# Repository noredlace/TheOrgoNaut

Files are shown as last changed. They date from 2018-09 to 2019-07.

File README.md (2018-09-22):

# TheOrgoNaut66

A design by u/lizardsticks

A an ergonomic ortholinear 60% board. Inspiration from the atreus with a twist on the modifiers and keys to fit most keycap designs. <br /> 

Nonstandard keycaps include the 2.25u Novelty on the left side. This keycap is meant to be used with either the Enter Key or a Novelty Enter Key. 

The left shift key was chosen to be a 2.75u with the right shift being a split shift 1.75u + 1u key.

I suppose the inner column 1u keycaps for 5,3 nd 5,4 could potentially be difficult to find, in the meantime the numpad of a keycap set should suffice.

This allows the keyboard to be symmetrical while having good compatibility with most base keycap sets.

KLE
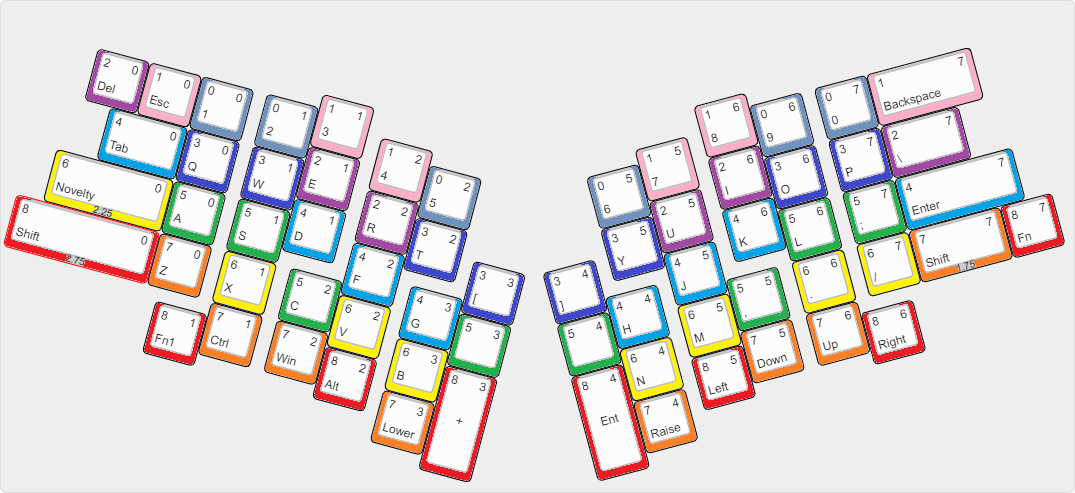
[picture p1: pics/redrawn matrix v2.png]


The color code helps identify the rows of diodes that will be used. The spacing allows for me to visualize the columns. The actual PCB won't have the spacing that you see on the left and right side. The triangle spacing in the middle will stay.

Before this, I had made the matrix based off the position of keys, which made tracing messy due to a multitude of crossed traces. Thus I made necessary changes to allow for cleaner traces and minimal vias.

You can also see the row and column numbers to visualize the schematic.

Schematic was done in a 9 x 8 layout. This is due to the 66 keys on the OrgoNaut. <br />
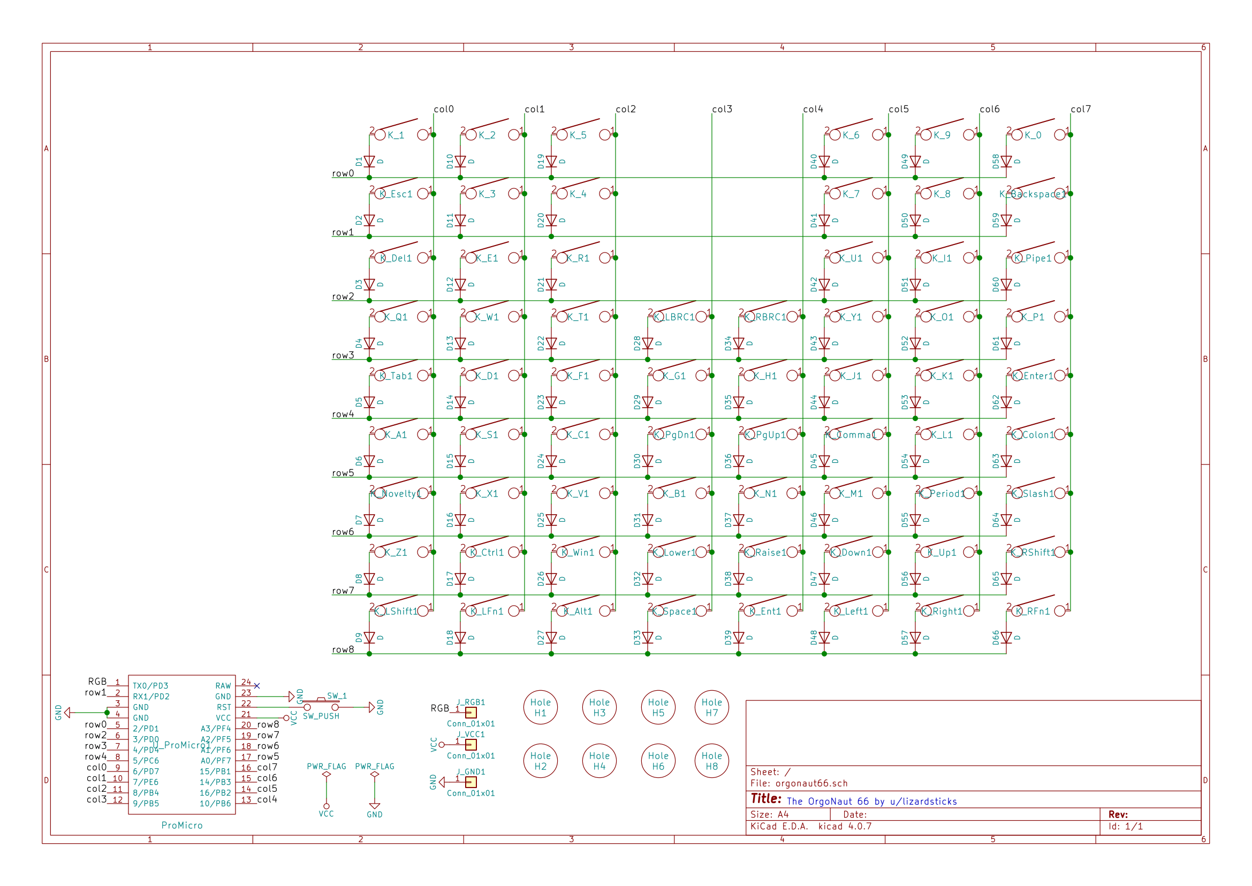
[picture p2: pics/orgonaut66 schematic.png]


PCB Dimensions are 148x362mm(5.81x14.25 inches) 
Front PCB
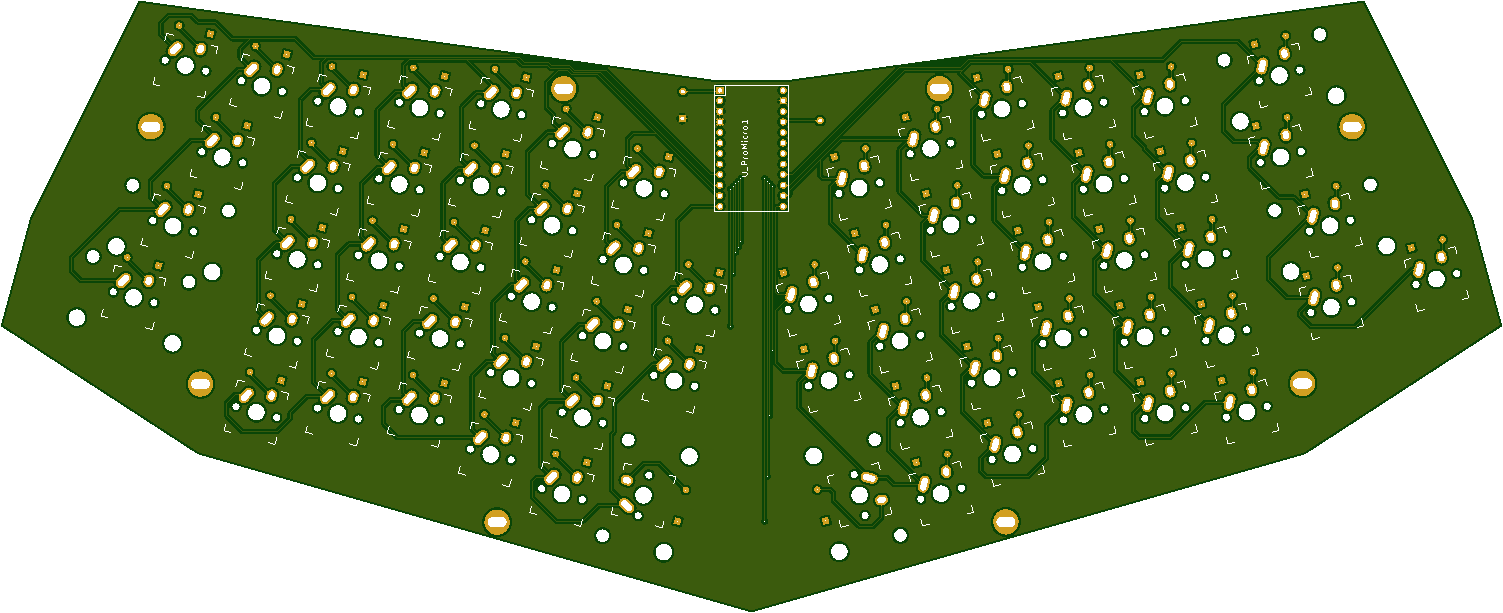
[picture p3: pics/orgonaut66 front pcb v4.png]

Back PCB
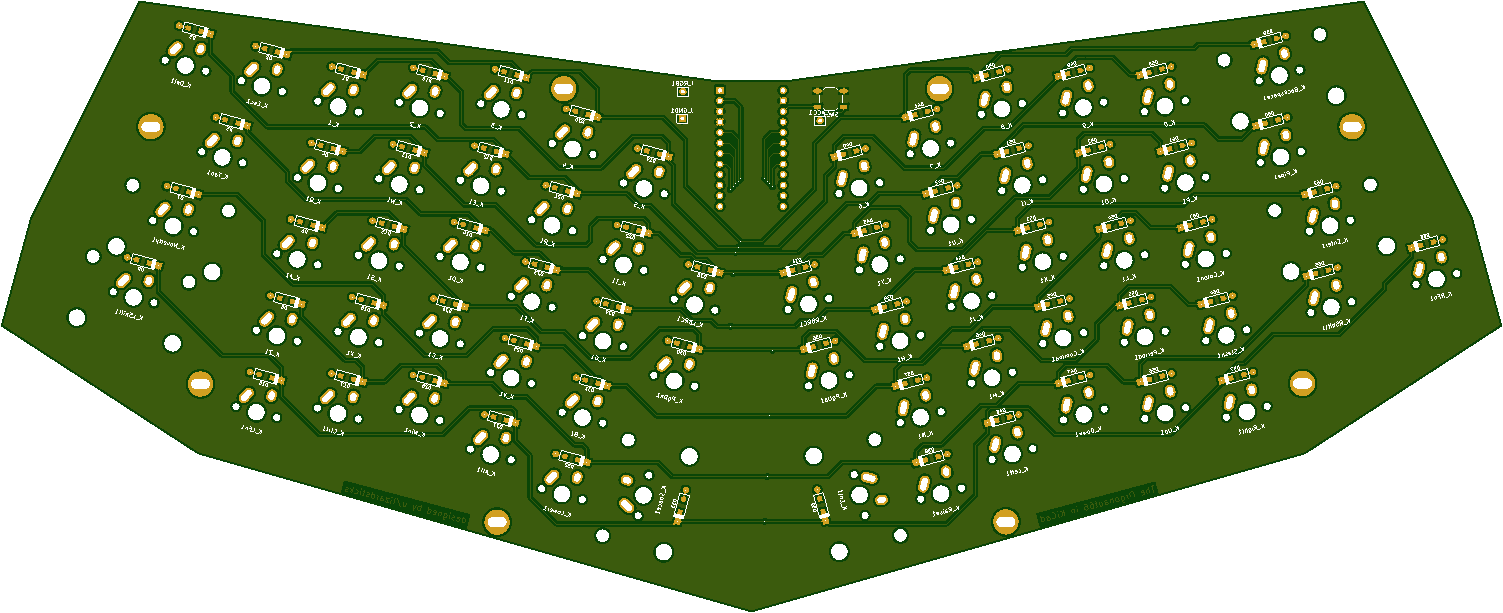
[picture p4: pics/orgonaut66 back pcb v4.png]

As you can see in the photos, the pcb is relatively clean in terms of the tracing. Of course its relative to how much of a mess my previous trace attempts have been.

Update v2 attempted to create aesthetically pleasing tracing. significant focus on how tracing to the pro micro 

Update v3 changed the pictures from KiCad's renderer to a gerber viewer provided by EasyEDA

Update v4 brought uniform ground planes to cover both front and back of the pcb. As well as changing the through hole footprints from m2 screw holes to pok3r style holes

# Major Update
The PCBs have been ordered and delivered courtesy of EasyEDA. The PCBs have been tested and all holes are currently registering correct keystrokes for the simple keyboard layout that has been made.

PCBs just delivered
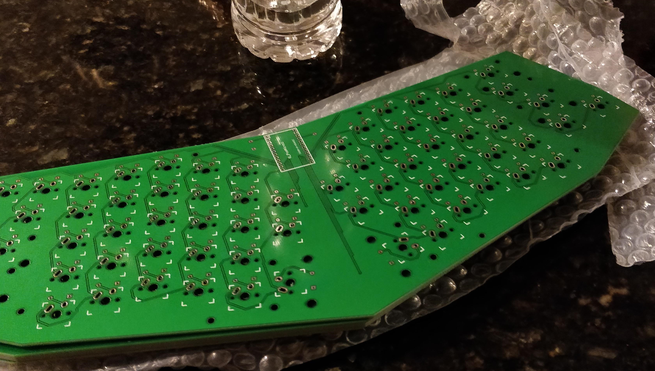
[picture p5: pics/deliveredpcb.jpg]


PCB Soldered with diodes and socketed pro micro
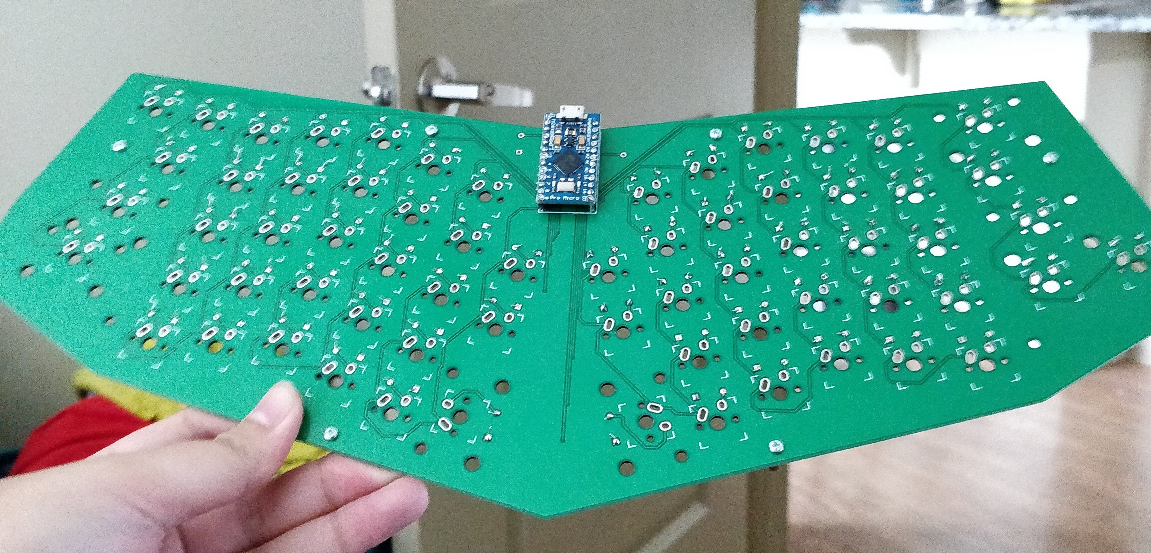
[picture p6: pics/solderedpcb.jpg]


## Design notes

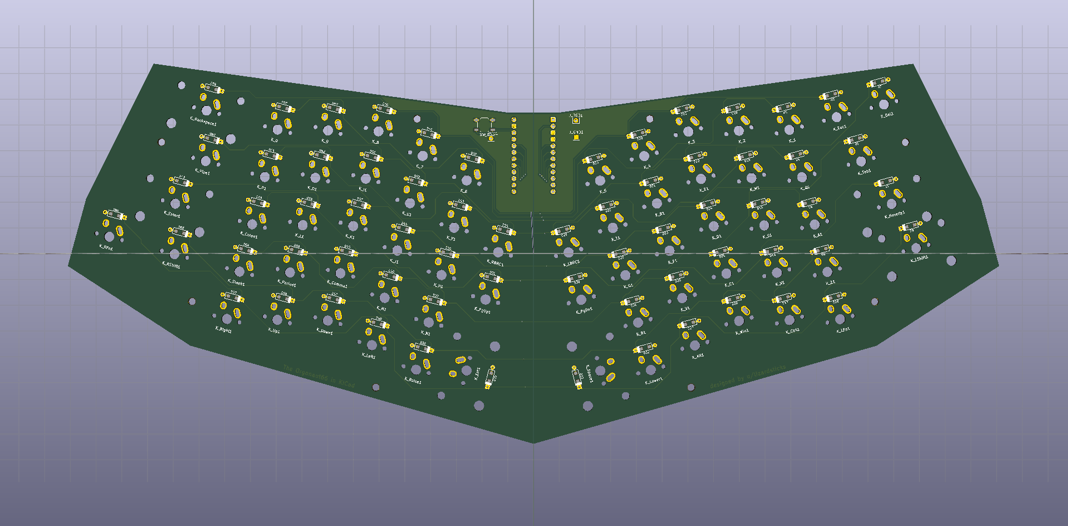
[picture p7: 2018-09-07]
pics/orgonaut66 back pcb v2.png

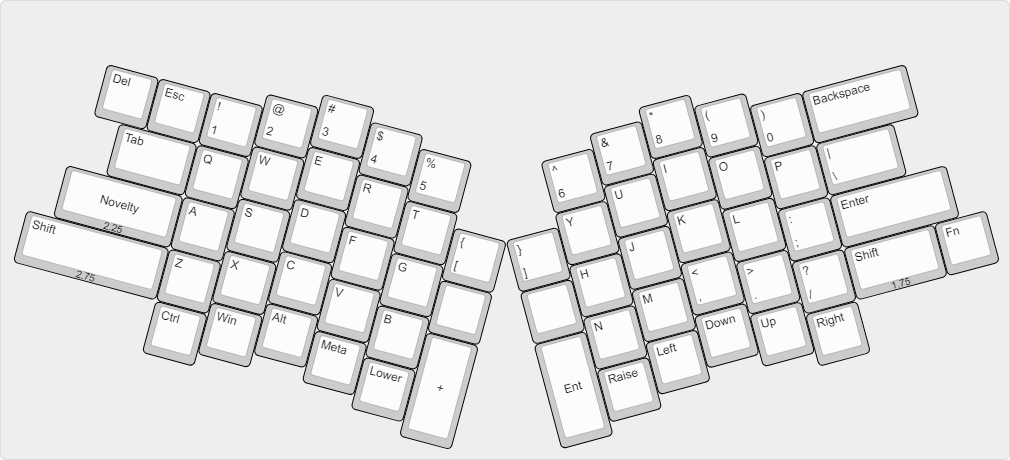
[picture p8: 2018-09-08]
pics/orgonaut layout.png

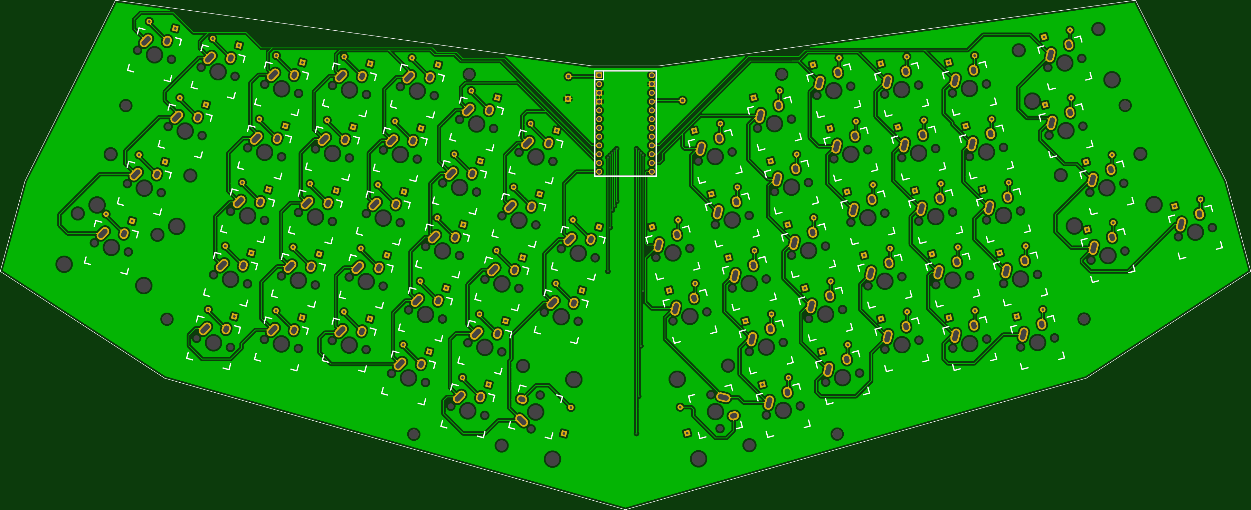
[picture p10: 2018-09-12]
pics/orgonaut66 front pcb v3.png

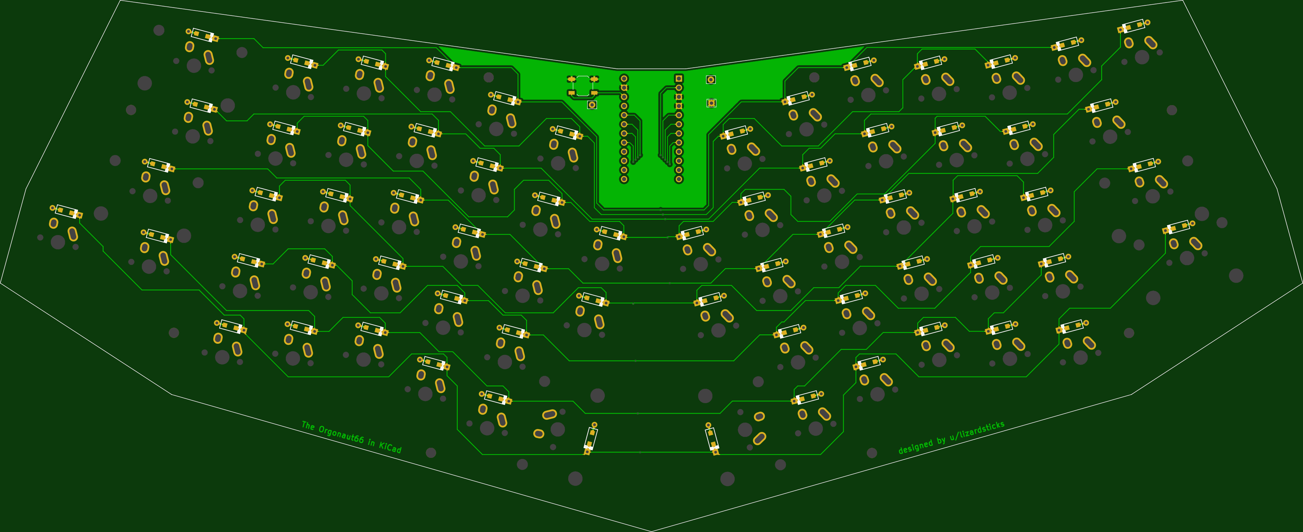
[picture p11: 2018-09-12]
pics/orgonaut66 back pcb v3.png

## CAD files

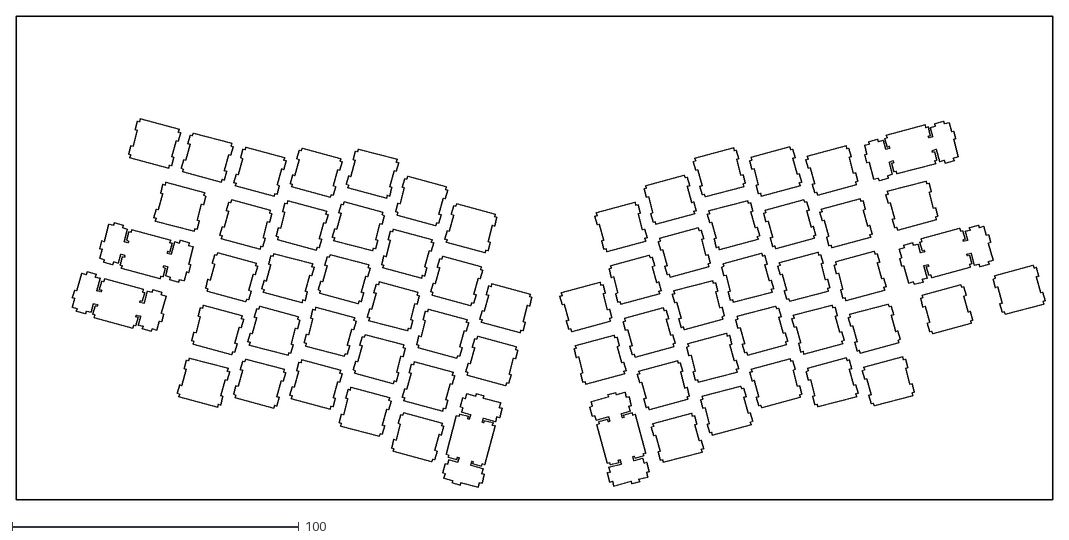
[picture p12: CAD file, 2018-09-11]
orgonaut66/fa1955e74fefcd2b1390044c22b81dd708fb88fe_switch.dxf
361.7 x 168.9

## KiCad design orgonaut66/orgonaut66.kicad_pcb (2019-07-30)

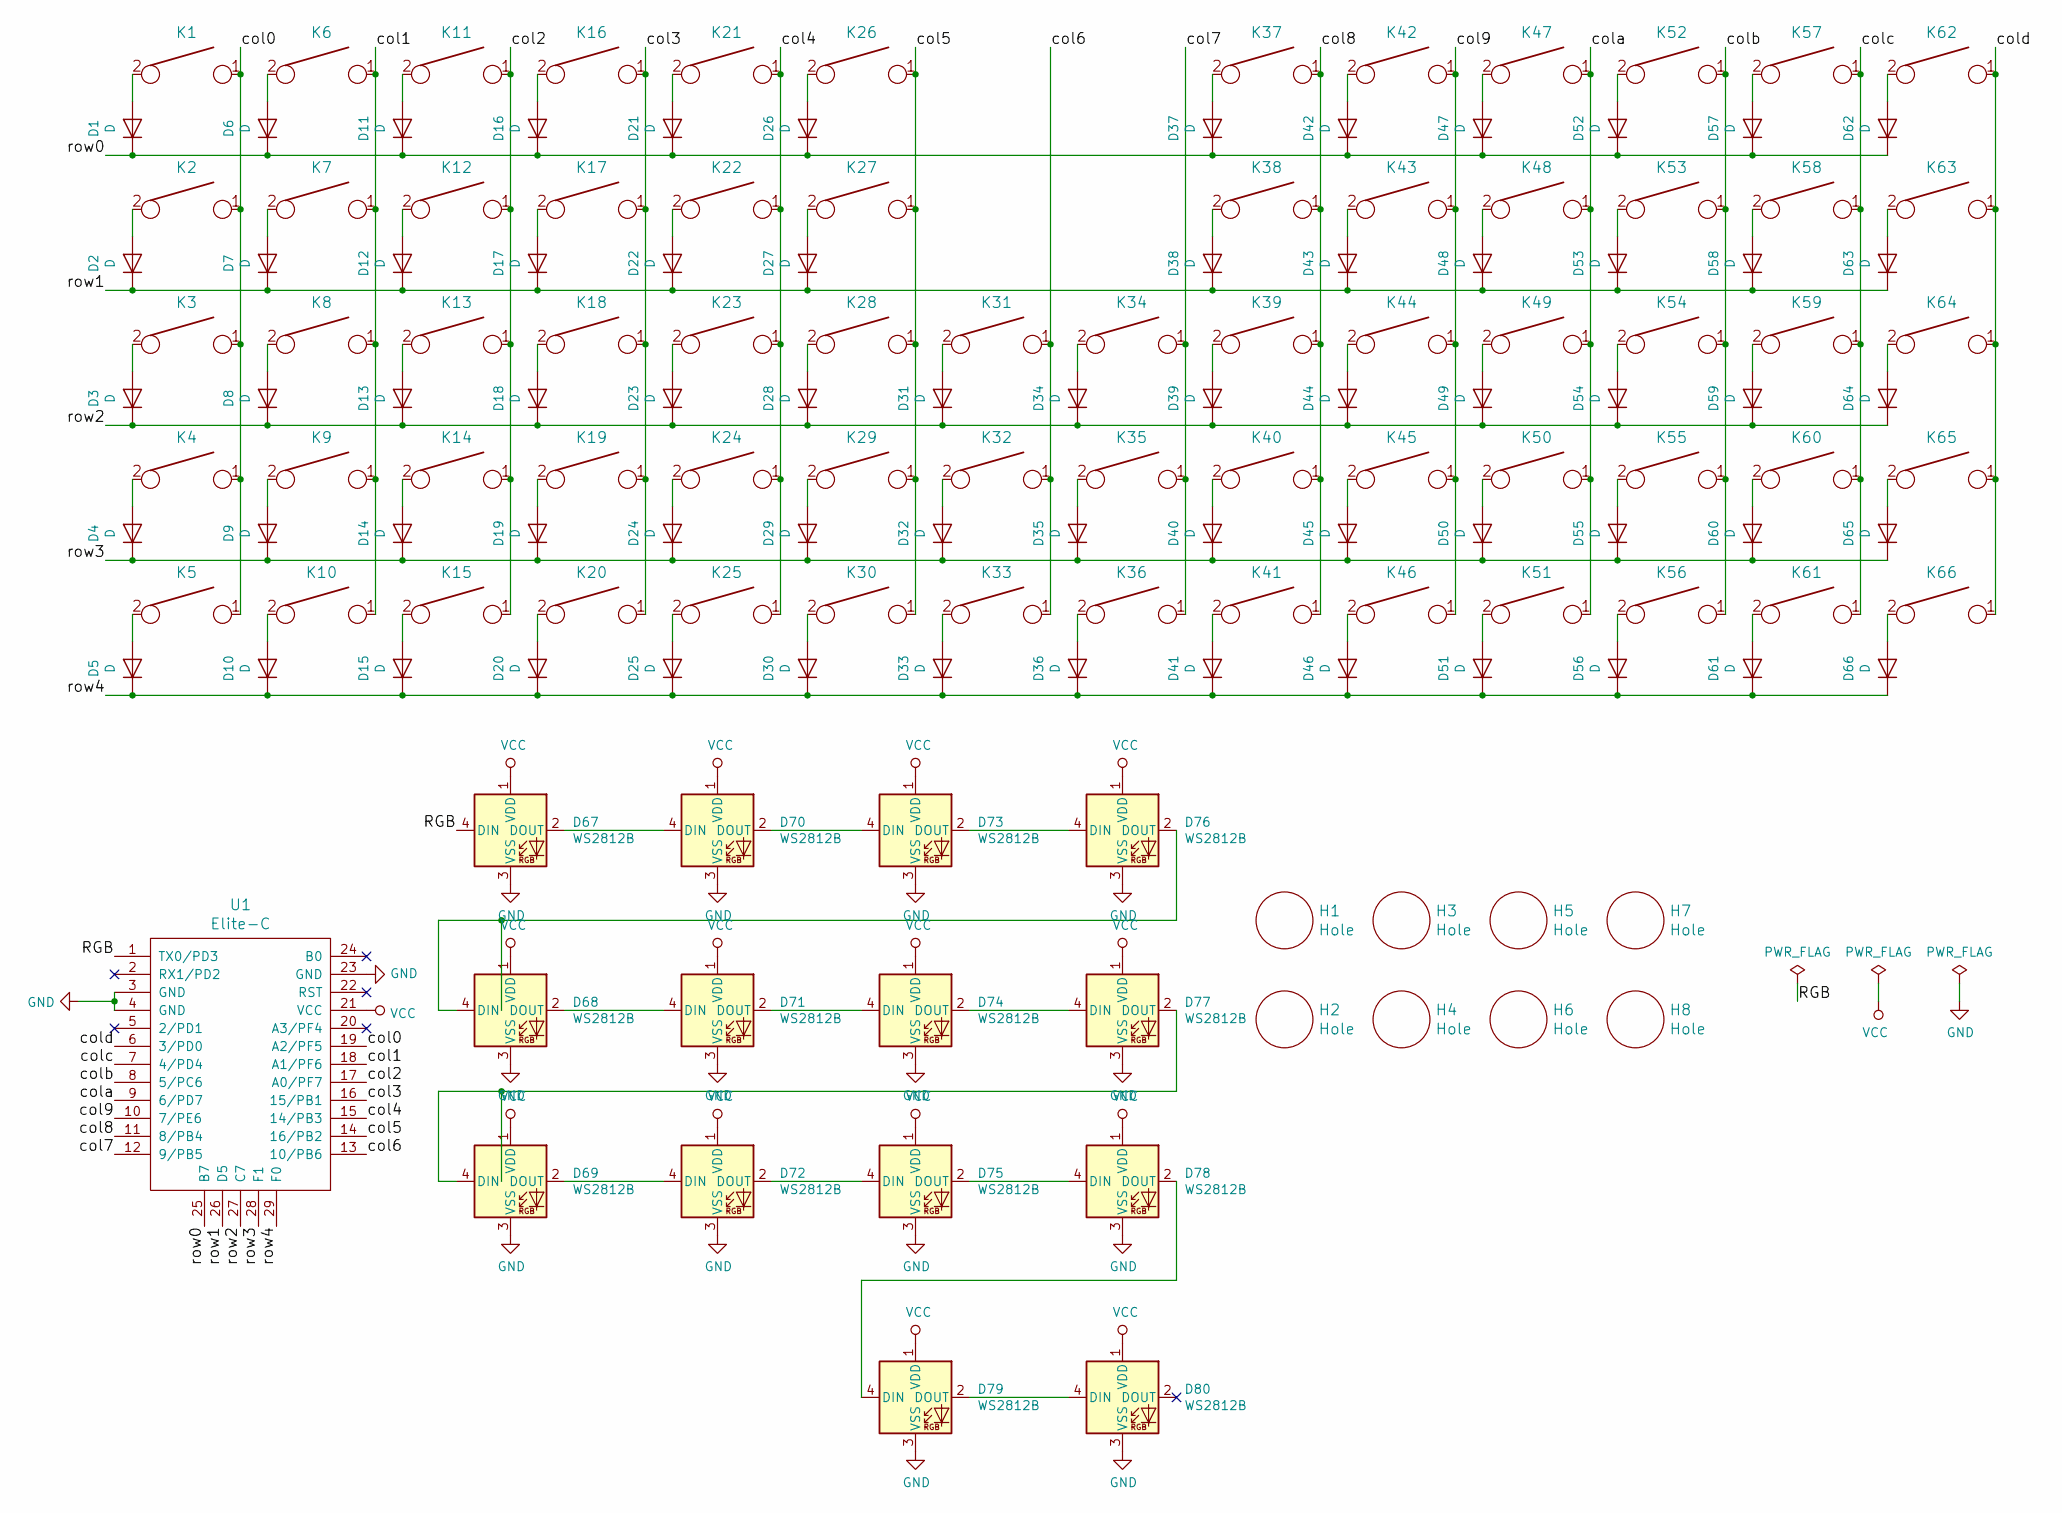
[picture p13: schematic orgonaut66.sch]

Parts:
D1, D2, D3, D4, D5, D6, D7, D8, D9, D10, D11, D12, D13, D14, D15, D16, D17, D18, D19, D20, D21, D22, D23, D24, D25, D26, D27, D28, D29, D30, D31, D32, D33, D34, D35, D36, D37, D38, D39, D40, D41, D42, D43, D44, D45, D46, D47, D48, D49, D50, D51, D52, D53, D54, D55, D56, D57, D58, D59, D60, D61, D62, D63, D64, D65, D66: D; D_SOD123_ThroughHole
D67, D68, D69, D70, D71, D72, D73, D74, D75, D76, D77, D78, D79, D80: WS2812B; RGBW_LED_5mm
H1, H2, H3, H4, H5, H6, H7, H8: Hole; Poker_oval_hole
K1, K2, K6, K7, K8, K9, K10, K11, K12, K13, K14, K15, K16, K17, K18, K19, K20, K21, K22, K23, K24, K25, K26, K27, K28, K29, K30, K31, K32, K34, K35, K37, K38, K39, K40, K41, K42, K43, K44, K45, K46, K47, K48, K49, K50, K51, K52, K53, K54, K55, K56, K57, K58, K59, K60, K61, K66: KEYSW; Mx_Alps_100
K3, K63: KEYSW; Mx_Alps_150
K4, K64: KEYSW; Mx_Alps_225
K5: KEYSW; Mx_Alps_275
K33, K36: KEYSW; Mx_Alps_200-dualside
K62: KEYSW; Mx_Alps_200
K65: KEYSW; Mx_Alps_175
U1: Elite-C; Elite-C-ZigZag

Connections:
/RGB: D67.4 (DIN), U1.1 (TX0/PD3)
/col0: K1.1, K2.1, K3.1, K4.1, K5.1, U1.19 (A2/PF5)
/col1: K6.1, K7.1, K8.1, K9.1, K10.1, U1.18 (A1/PF6)
/col2: K11.1, K12.1, K13.1, K14.1, K15.1, U1.17 (A0/PF7)
/col3: K16.1, K17.1, K18.1, K19.1, K20.1, U1.16 (15/PB1)
/col4: K21.1, K22.1, K23.1, K24.1, K25.1, U1.15 (14/PB3)
/col5: K26.1, K27.1, K28.1, K29.1, K30.1, U1.14 (16/PB2)
/col6: K31.1, K32.1, K33.1, U1.13 (10/PB6)
/col7: K34.1, K35.1, K36.1, U1.12 (9/PB5)
/col8: K37.1, K38.1, K39.1, K40.1, K41.1, U1.11 (8/PB4)
/col9: K42.1, K43.1, K44.1, K45.1, K46.1, U1.10 (7/PE6)
/cola: K47.1, K48.1, K49.1, K50.1, K51.1, U1.9 (6/PD7)
/colb: K52.1, K53.1, K54.1, K55.1, K56.1, U1.8 (5/PC6)
/colc: K57.1, K58.1, K59.1, K60.1, K61.1, U1.7 (4/PD4)
/cold: K62.1, K63.1, K64.1, K65.1, K66.1, U1.6 (3/PD0)
/row0: D1.1 (K), D6.1 (K), D11.1 (K), D16.1 (K), D21.1 (K), D26.1 (K), D37.1 (K), D42.1 (K), D47.1 (K), D52.1 (K), D57.1 (K), D62.1 (K), U1.25 (B7)
/row1: D2.1 (K), D7.1 (K), D12.1 (K), D17.1 (K), D22.1 (K), D27.1 (K), D38.1 (K), D43.1 (K), D48.1 (K), D53.1 (K), D58.1 (K), D63.1 (K), U1.26 (D5)
/row2: D3.1 (K), D8.1 (K), D13.1 (K), D18.1 (K), D23.1 (K), D28.1 (K), D31.1 (K), D34.1 (K), D39.1 (K), D44.1 (K), D49.1 (K), D54.1 (K), D59.1 (K), D64.1 (K), U1.27 (C7)
/row3: D4.1 (K), D9.1 (K), D14.1 (K), D19.1 (K), D24.1 (K), D29.1 (K), D32.1 (K), D35.1 (K), D40.1 (K), D45.1 (K), D50.1 (K), D55.1 (K), D60.1 (K), D65.1 (K), U1.28 (F1)
/row4: D5.1 (K), D10.1 (K), D15.1 (K), D20.1 (K), D25.1 (K), D30.1 (K), D33.1 (K), D36.1 (K), D41.1 (K), D46.1 (K), D51.1 (K), D56.1 (K), D61.1 (K), D66.1 (K), U1.29 (F0)
GND: D67.3 (VSS), D68.3 (VSS), D69.3 (VSS), D70.3 (VSS), D71.3 (VSS), D72.3 (VSS), D73.3 (VSS), D74.3 (VSS), D75.3 (VSS), D76.3 (VSS), D77.3 (VSS), D78.3 (VSS), D79.3 (VSS), D80.3 (VSS), U1.3 (GND), U1.4 (GND), U1.23 (GND)
unnamed: D1.2 (A), K1.2
unnamed: D2.2 (A), K2.2
unnamed: D3.2 (A), K3.2
unnamed: D4.2 (A), K4.2
unnamed: D5.2 (A), K5.2
unnamed: D6.2 (A), K6.2
unnamed: D7.2 (A), K7.2
unnamed: D8.2 (A), K8.2
unnamed: D9.2 (A), K9.2
unnamed: D10.2 (A), K10.2
unnamed: D11.2 (A), K11.2
unnamed: D12.2 (A), K12.2
unnamed: D13.2 (A), K13.2
unnamed: D14.2 (A), K14.2
unnamed: D15.2 (A), K15.2
unnamed: D16.2 (A), K16.2
unnamed: D17.2 (A), K17.2
unnamed: D18.2 (A), K18.2
unnamed: D19.2 (A), K19.2
unnamed: D20.2 (A), K20.2
unnamed: D21.2 (A), K21.2
unnamed: D22.2 (A), K22.2
unnamed: D23.2 (A), K23.2
unnamed: D24.2 (A), K24.2
unnamed: D25.2 (A), K25.2
unnamed: D26.2 (A), K26.2
unnamed: D27.2 (A), K27.2
unnamed: D28.2 (A), K28.2
unnamed: D29.2 (A), K29.2
unnamed: D30.2 (A), K30.2
unnamed: D31.2 (A), K31.2
unnamed: D32.2 (A), K32.2
unnamed: D33.2 (A), K33.2
unnamed: D34.2 (A), K34.2
unnamed: D35.2 (A), K35.2
unnamed: D36.2 (A), K36.2
unnamed: D37.2 (A), K37.2
unnamed: D38.2 (A), K38.2
unnamed: D39.2 (A), K39.2
unnamed: D40.2 (A), K40.2
unnamed: D41.2 (A), K41.2
unnamed: D42.2 (A), K42.2
unnamed: D43.2 (A), K43.2
unnamed: D44.2 (A), K44.2
unnamed: D45.2 (A), K45.2
unnamed: D46.2 (A), K46.2
unnamed: D47.2 (A), K47.2
unnamed: D48.2 (A), K48.2
unnamed: D49.2 (A), K49.2
unnamed: D50.2 (A), K50.2
unnamed: D51.2 (A), K51.2
unnamed: D52.2 (A), K52.2
unnamed: D53.2 (A), K53.2
unnamed: D54.2 (A), K54.2
unnamed: D55.2 (A), K55.2
unnamed: D56.2 (A), K56.2
unnamed: D57.2 (A), K57.2
unnamed: D58.2 (A), K58.2
unnamed: D59.2 (A), K59.2
unnamed: D60.2 (A), K60.2
unnamed: D61.2 (A), K61.2
unnamed: D62.2 (A), K62.2
unnamed: D63.2 (A), K63.2
unnamed: D64.2 (A), K64.2
unnamed: D65.2 (A), K65.2
unnamed: D66.2 (A), K66.2
unnamed: D67.2 (DOUT), D70.4 (DIN)
unnamed: D68.2 (DOUT), D71.4 (DIN)
unnamed: D68.4 (DIN), D76.2 (DOUT)
unnamed: D69.2 (DOUT), D72.4 (DIN)
unnamed: D69.4 (DIN), D77.2 (DOUT)
unnamed: D70.2 (DOUT), D73.4 (DIN)
unnamed: D71.2 (DOUT), D74.4 (DIN)
unnamed: D72.2 (DOUT), D75.4 (DIN)
unnamed: D73.2 (DOUT), D76.4 (DIN)
unnamed: D74.2 (DOUT), D77.4 (DIN)
unnamed: D75.2 (DOUT), D78.4 (DIN)
unnamed: D78.2 (DOUT), D79.4 (DIN)
unnamed: D79.2 (DOUT), D80.4 (DIN)
VCC: D67.1 (VDD), D68.1 (VDD), D69.1 (VDD), D70.1 (VDD), D71.1 (VDD), D72.1 (VDD), D73.1 (VDD), D74.1 (VDD), D75.1 (VDD), D76.1 (VDD), D77.1 (VDD), D78.1 (VDD), D79.1 (VDD), D80.1 (VDD), U1.21 (VCC)

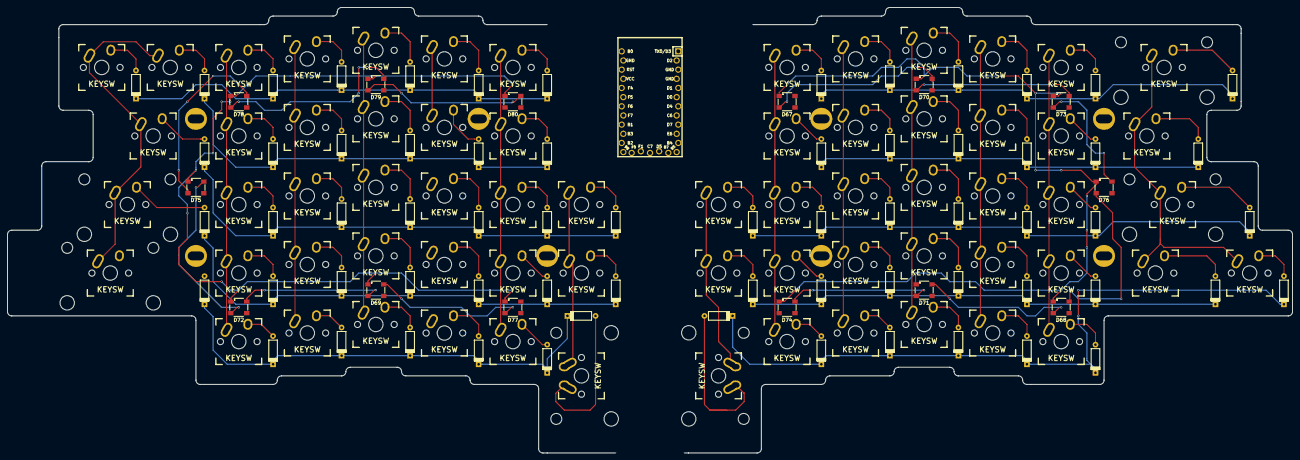
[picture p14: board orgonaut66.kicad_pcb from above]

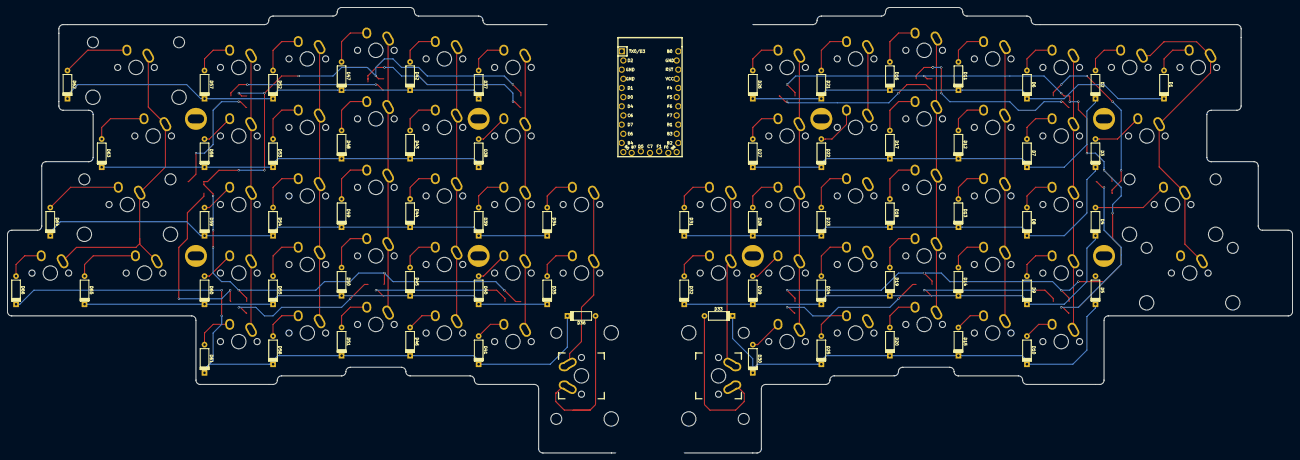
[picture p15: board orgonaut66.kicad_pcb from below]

Board: 2 copper layers, 356.2 x 123.5 mm, 155 parts (67 on the bottom side), 101 nets.

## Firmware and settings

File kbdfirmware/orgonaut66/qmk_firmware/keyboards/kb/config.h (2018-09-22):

#ifndef CONFIG_H
#define CONFIG_H

#include "config_common.h"

/* USB Device descriptor parameter */
#define VENDOR_ID       0xFEED
#define PRODUCT_ID      0x6060
#define DEVICE_VER      0x0001
#define MANUFACTURER    qmkbuilder
#define PRODUCT         keyboard
#define DESCRIPTION     Keyboard

/* key matrix size */
#define MATRIX_ROWS 9
#define MATRIX_COLS 8

/* key matrix pins */
#define MATRIX_ROW_PINS { D1, D2, D0, D4, C6, F7, F6, F5, F4 }
#define MATRIX_COL_PINS { D7, E6, B4, B5, B6, B2, B3, B1 }
#define UNUSED_PINS

/* COL2ROW or ROW2COL */
#define DIODE_DIRECTION COL2ROW

/* number of backlight levels */

#ifdef BACKLIGHT_PIN
#define BACKLIGHT_LEVELS 3
#endif

/* Set 0 if debouncing isn't needed */
#define DEBOUNCING_DELAY 5

/* Mechanical locking support. Use KC_LCAP, KC_LNUM or KC_LSCR instead in keymap */
#define LOCKING_SUPPORT_ENABLE

/* Locking resynchronize hack */
#define LOCKING_RESYNC_ENABLE

/* key combination for command */
#define IS_COMMAND() ( \
    keyboard_report->mods == (MOD_BIT(KC_LSHIFT) | MOD_BIT(KC_RSHIFT)) \
)

/* prevent stuck modifiers */
#define PREVENT_STUCK_MODIFIERS

#define RGB_DI_PIN D3
#ifdef RGB_DI_PIN
#define RGBLIGHT_ANIMATIONS
#define RGBLED_NUM 0
#define RGBLIGHT_HUE_STEP 8
#define RGBLIGHT_SAT_STEP 8
#define RGBLIGHT_VAL_STEP 8
#endif

#endif

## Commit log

2018-09-06 push beginning of orgonaut 66 pcb
    [orgonaut66.kicad_pcb, orgonaut66.sch]
2018-09-07 finsh tracing
    [orgonaut66.kicad_pcb]
2018-09-07 modify tracings & add gerber
    [orgonaut66-B.Cu.gbl, orgonaut66-B.Mask.gbs, orgonaut66-B.Paste.gbp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]
2018-09-07 update gerber
    [orgonaut66-B.Cu.gbl, orgonaut66-B.Mask.gbs, orgonaut66-B.Paste.gbp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]
2018-09-07 clean up pcb, update gerber
    [orgonaut66-B.Cu.gbl, orgonaut66-B.Mask.gbs, orgonaut66-B.Paste.gbp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]
2018-09-07 push v2 changes
    [orgonaut66-B.Cu.gbl, orgonaut66-B.Mask.gbs, orgonaut66-B.Paste.gbp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]
2018-09-08 new gerber
    [orgonaut66-B.Cu.gbl, orgonaut66-B.Mask.gbs, orgonaut66-B.Paste.gbp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]
2018-09-11 update step
    [fa1955e74fefcd2b1390044c22b81dd708fb88fe_switch.dxf]
2018-09-12 push new gerber/ reroute space
    [orgonaut66-B.Cu.gbl, orgonaut66-B.Mask.gbs, orgonaut66-B.Paste.gbp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]
2018-09-12 redo gerber
    [orgonaut66-B.Cu.gbl, orgonaut66-B.Mask.gbs, orgonaut66-B.Paste.gbp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]
2018-09-12 update save
    [orgonaut66.kicad_pcb]
2018-09-21 update bottom ground plane
    [orgonaut66.kicad_pcb]
2018-09-22 modify ground planes, change holes to pok3r
    [_saved_orgonaut66.sch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]
2018-09-22 push new pcb pictures
2018-09-25 update pcb
    [orgonaut66.kicad_pcb]
2019-07-30 update orgonaut v4 for elite c
    [orgonaut66-2019-07-29-21-22-15.sch, orgonaut66.kicad_pcb, orgonaut66.sch]
